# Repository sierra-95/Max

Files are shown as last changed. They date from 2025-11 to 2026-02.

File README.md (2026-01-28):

# Project Max

## Table of Contents

1. [Introduction](#introduction)
2. [Robot Variants](#robot-variants)
3. [Project Implementation](#project-implementation)
4. [Getting Started](#getting-started)
5. [Launching Max](#launching-max)
6. [License](#license)
7. [Contributors](#contributors)

---

## Introduction

**Max** is an Autonomous Mobile Robot (AMR) designed for **mapping, localization, and autonomous navigation** using **ROS 2 Humble Hawksbill**.

The project explores both **LiDAR-based SLAM** and **visual SLAM (VSLAM)**, along with real-world robotic tasks such as object detection and agricultural disease detection.

---

## Robot Variants

Two physical versions of Max were developed:

* **Skid-Steer Robot**

  * LiDAR-based SLAM
  * Autonomous navigation using Nav2
  * [Potato disease detection](https://github.com/sierra-95/potato_disease_detection) and Color cube detection using Logitech camera
  * Mechanical loading and offloading mechanism

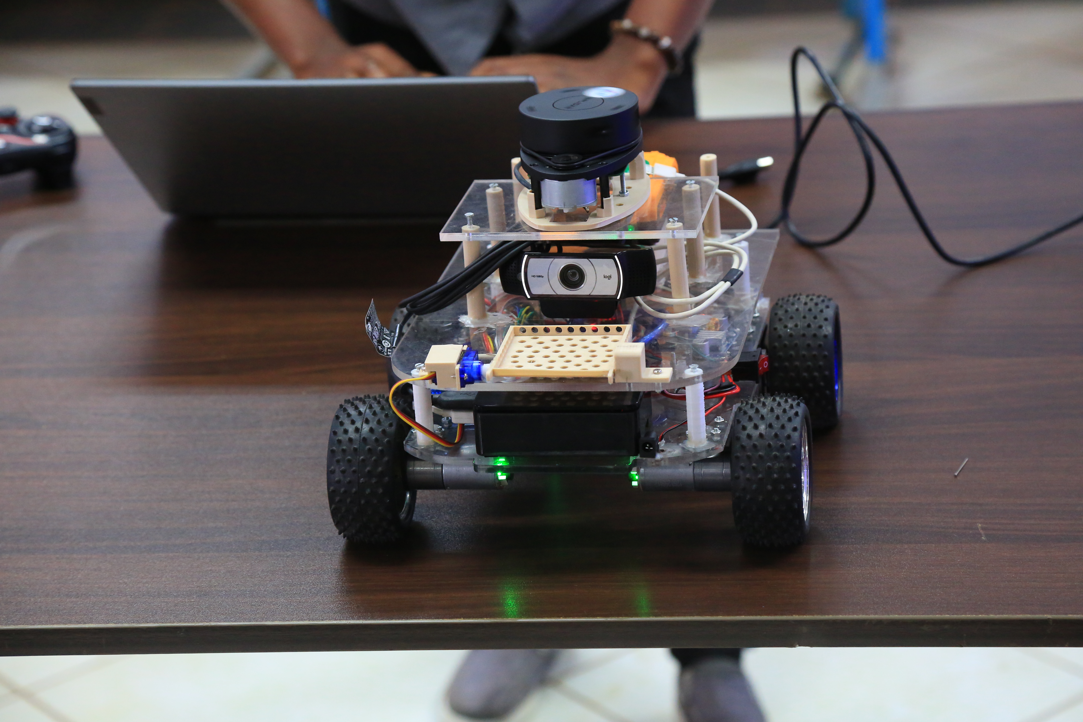
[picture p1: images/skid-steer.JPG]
Skid Steer


* **Differential Drive Robot - Beta**

  * LiDAR-based SLAM
  * Visual SLAM (VSLAM) using depth camera
  * Emergency stop button (motor cutoff)
  * Software-based proximity safety: reduces speed as the robot approaches obstacles, with RGB LED indication

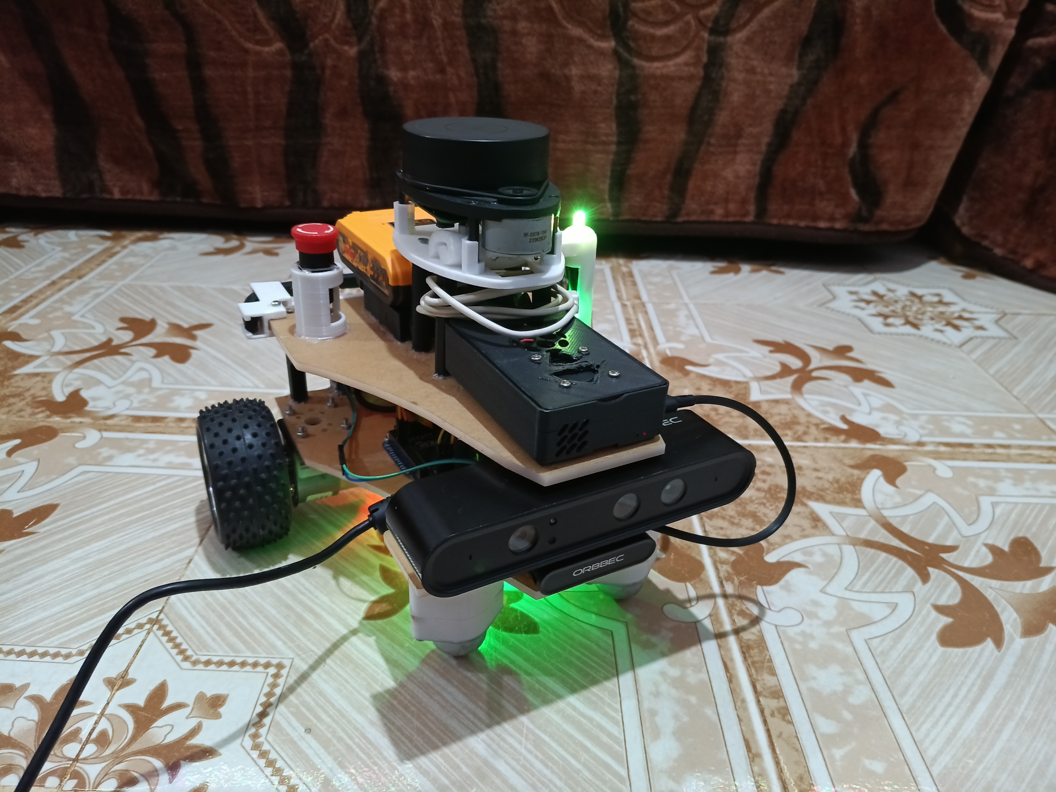
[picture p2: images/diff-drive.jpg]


---

## Project Implementation

### 1. Hardware Components

* **Raspberry Pi 4** – Main onboard computer
* **RPLidar A1** – 2D LiDAR for SLAM and navigation
* **Orbbec Astra Pro Depth Camera** – Used for VSLAM
* **Logitech C290 USB Camera** – Used for potato disease detection and color cube detection
* **JGB37-520 12V 110 RPM DC Motors (with encoders)**
* **L298N Motor Driver**
* **20V 2A Ingco Drill Battery** – Power source
* **Arduino Mega 2560** – Low-level motor control and encoder processing

---

### 2. Electrical design
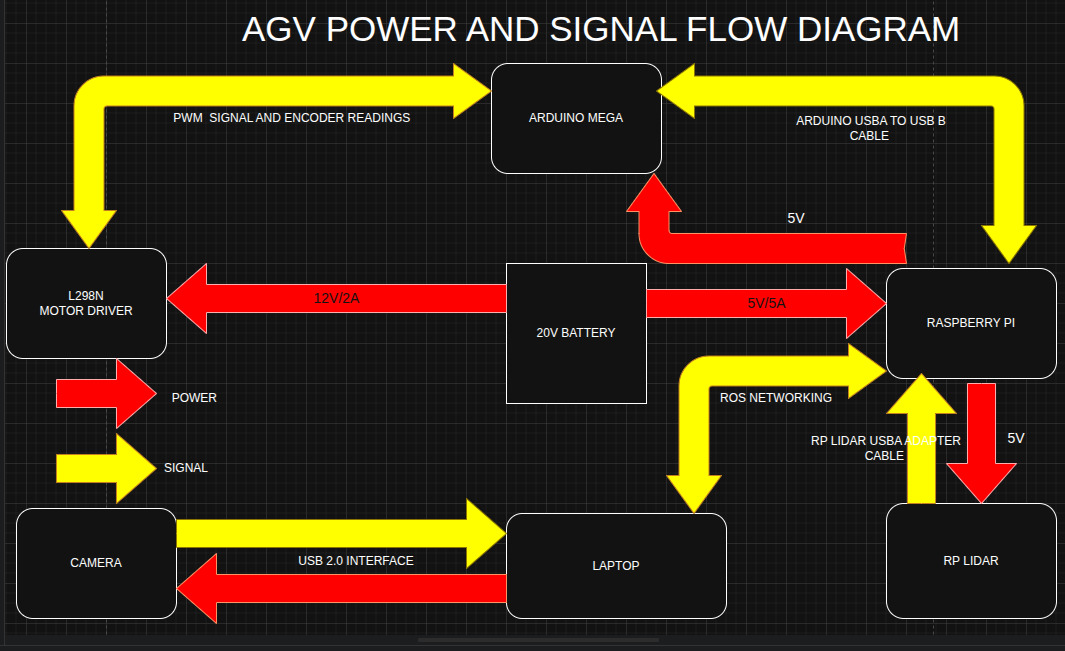
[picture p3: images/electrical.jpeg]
PCB

### 3. Digital Twin

A **Digital Twin** is a virtual representation of the physical robot and its environment.

In Project Max:

* **Gazebo** was used for physics-based simulation

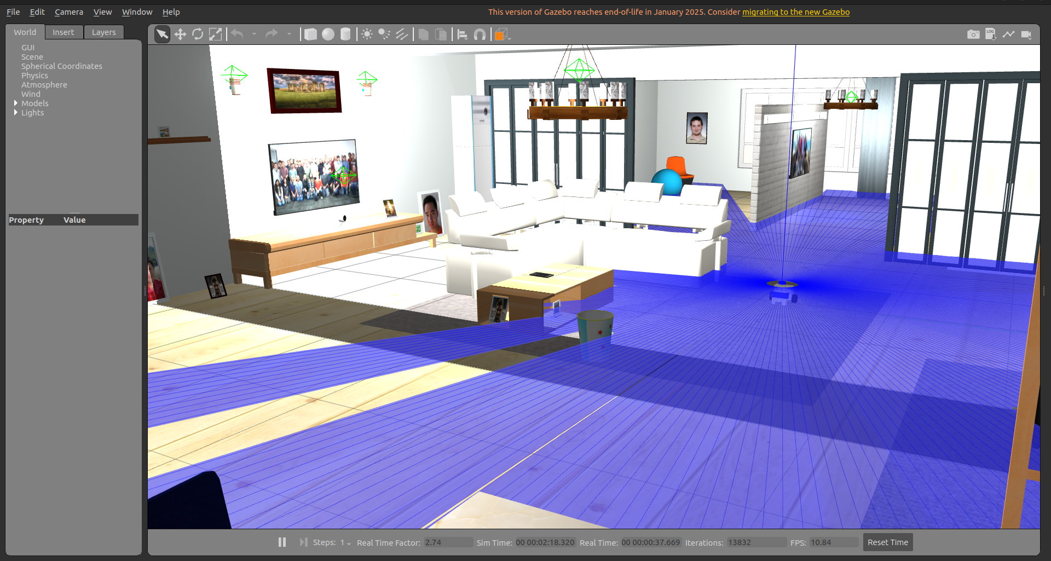
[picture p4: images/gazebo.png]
Gazebo


* **RViz** was used for visualization of:

  * Robot state
  * TF Structure
  * Maps and navigation goals

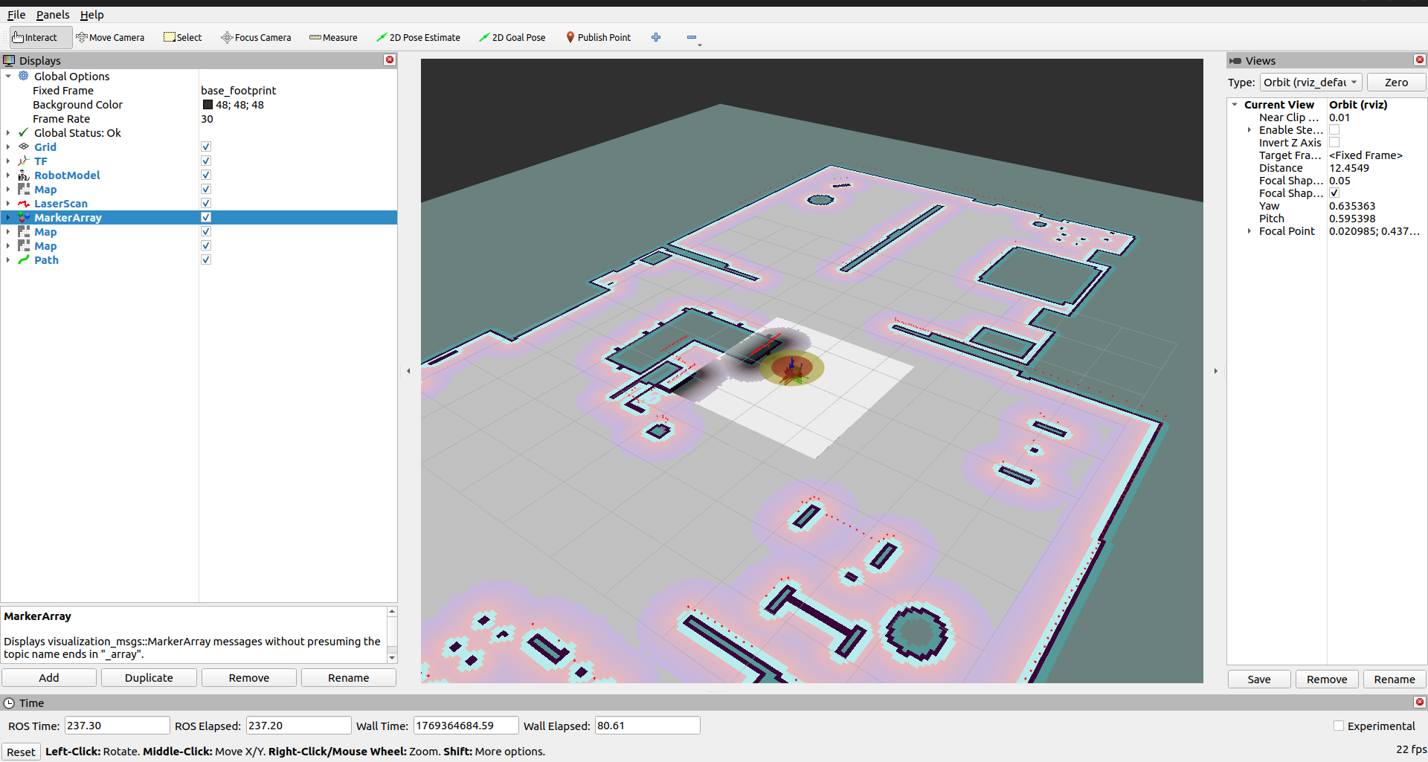
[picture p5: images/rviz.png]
Rviz

#### TF tree
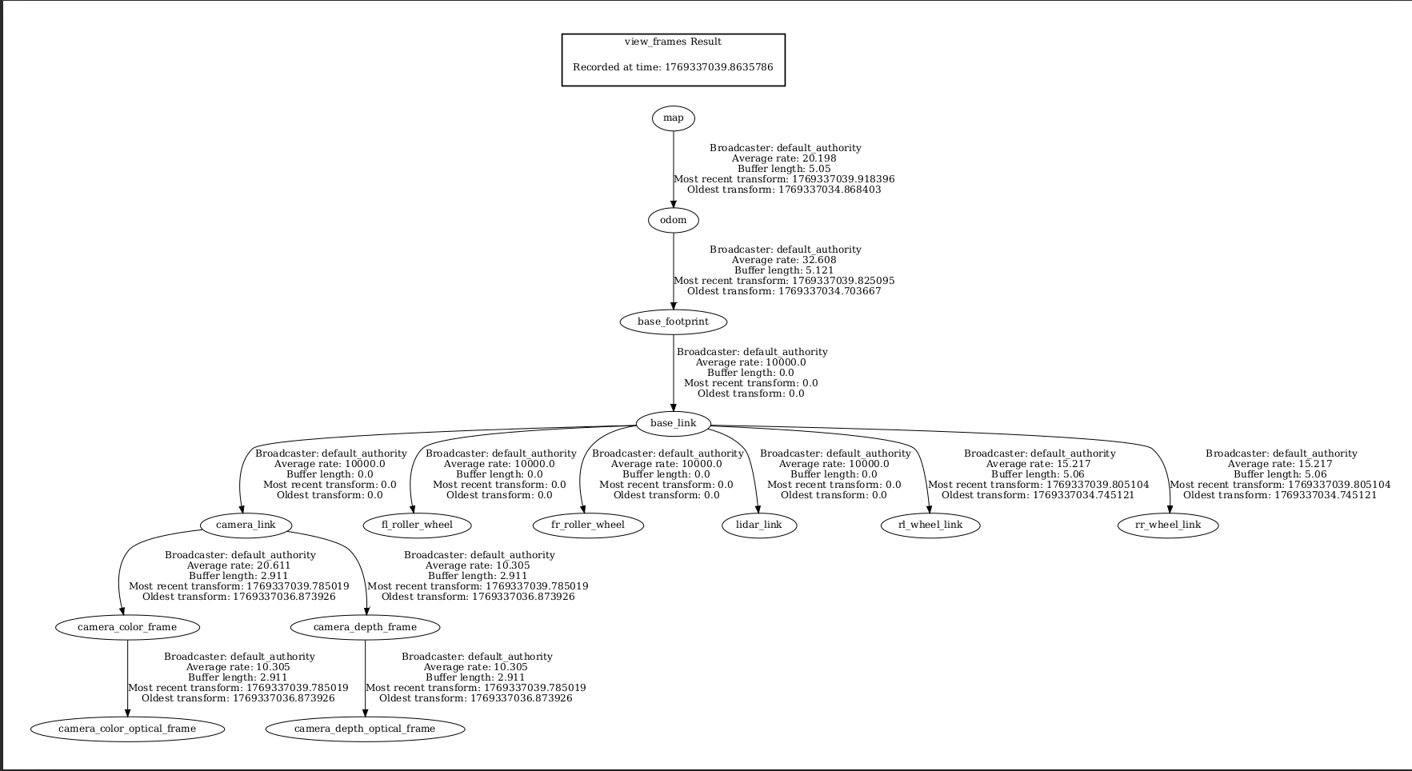
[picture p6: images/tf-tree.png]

---
### 4. SLAM

**Simultaneous Localization and Mapping (SLAM)** is the process of building a map of an unknown environment while simultaneously estimating the robot’s position within that map.

In Max:

* A **2D occupancy grid map** was generated using **LiDAR scans** and **Wheel odometry**, computed from encoder counts
* The resulting map was later used by **Nav2** for autonomous navigation and path planning

---

### 5. Visual SLAM (VSLAM)

**Visual SLAM (VSLAM)** uses camera data instead of (or in addition to) LiDAR.

In this approach:

* A **3D map or point cloud** is built using a **depth camera**.
* Compared to 2D SLAM, VSLAM provides more spatial information

> Note: Although LiDAR–VSLAM sensor fusion is possible, this project used **VSLAM independently** without fusion.

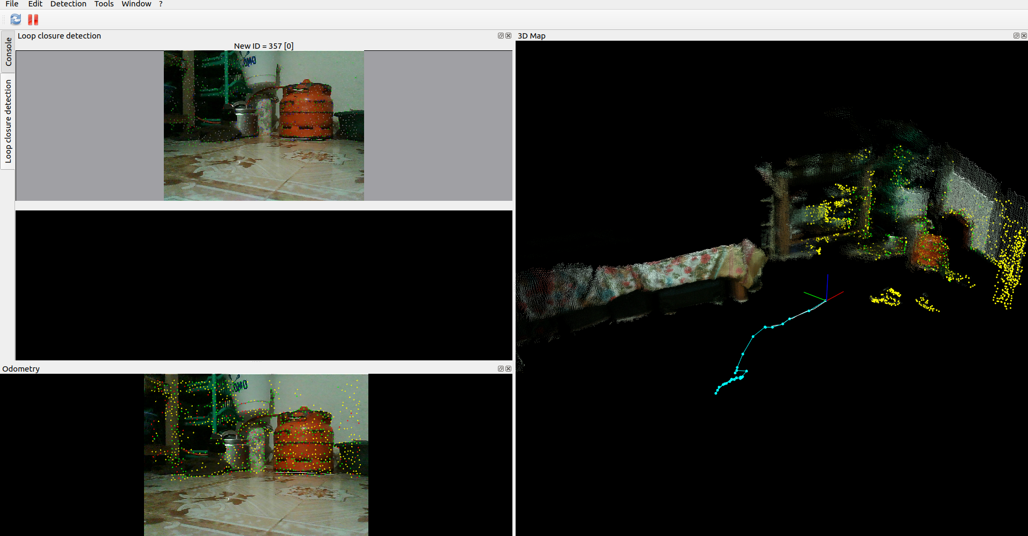
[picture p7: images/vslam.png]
Vslam


---

## Getting Started

### Clone the Repository

```bash
# Create workspace
mkdir -p max_ws/src && cd max_ws/src

# Clone repository
git clone https://github.com/sierra-95/Max.git
```

---

### Install Dependencies

```bash
# Update ROS dependency database
sudo rosdep update

# Install dependencies
rosdep install --from-paths src --ignore-src -r -y
```

---

### Build the Workspace

```bash
# Checkout the preferred branch
git checkout main

# Build the packages
colcon build --symlink-install
. install/setup.bash
```

---

## Launching Max

### Simulated Robot

```bash
ros2 launch max_bringup max.simulated.launch.py world_name:=small_house
```

---

### Real Robot

#### On the Raspberry Pi

```bash
ros2 launch rplidar_ros rplidar_a1_launch.py serial_port:=/dev/ttyUSB0 serial_baudrate:=115200 frame_id:=lidar_link
```

```bash
#Add the argument `use_rtab:=true` if using VSLAM.
ros2 launch max_bringup max.launch.py
```
#### On the Laptop

```bash
#Add the argument `use_rtab:=true` if using VSLAM.
ros2 launch max_bringup max.launch.py use_master:=true

# If using VSLAM
ros2 launch astra_camera astra_pro.launch.xml
```

---

## License

This project is **open source**.

## Contributors
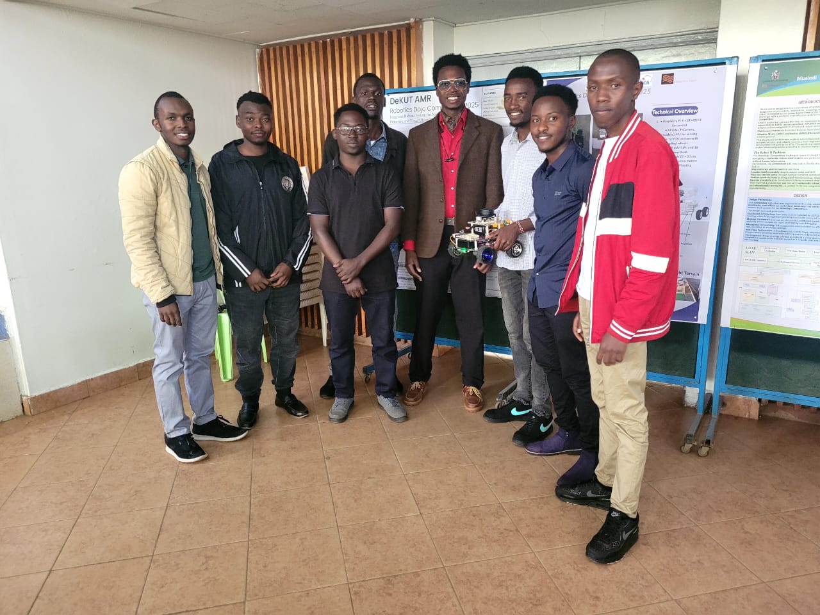
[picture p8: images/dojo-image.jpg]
Dojo Image


| Name | Profile |
|---|---|
| Michael Machohi | [sierra-95](https://github.com/sierra-95) |
| Paul Migwi | [Paul-Migwi](https://github.com/Paul-Migwi) |
| James Gathirwa  | [gathirwa011a](https://www.linkedin.com/in/gathirwa011a) |
| Brian Kiprono | [Kiprono1385](https://github.com/Kiprono1385) |
| Moses Mwangi | [moses-kangethe](https://www.linkedin.com/in/moses-kangethe) |
| Zebby Akach | [ZEBAYA](https://github.com/ZEBAYA) |

---

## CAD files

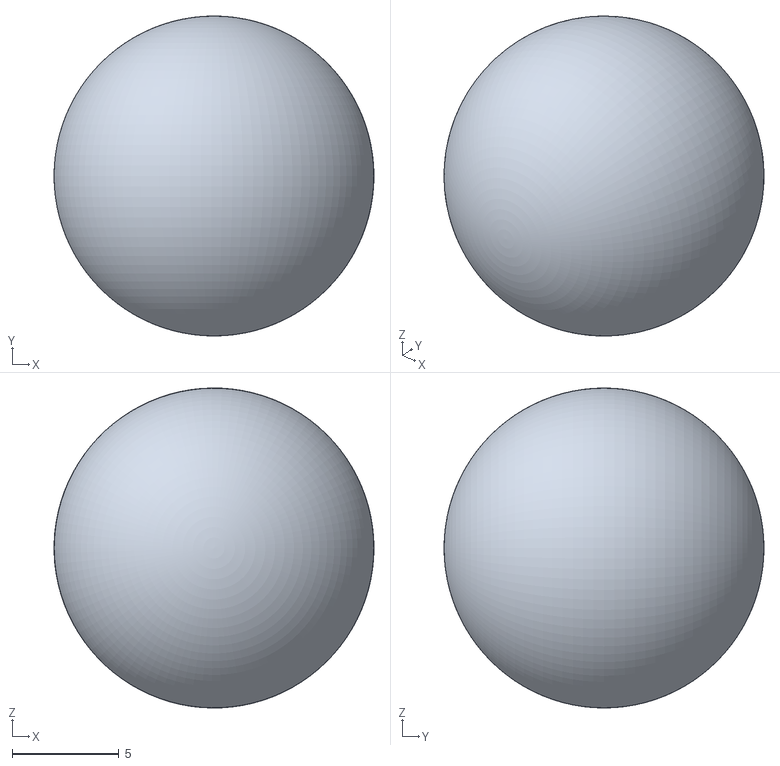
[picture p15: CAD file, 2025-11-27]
max_description/meshes/fl_roller_wheel.stl
15.0 x 15.0 x 15.0

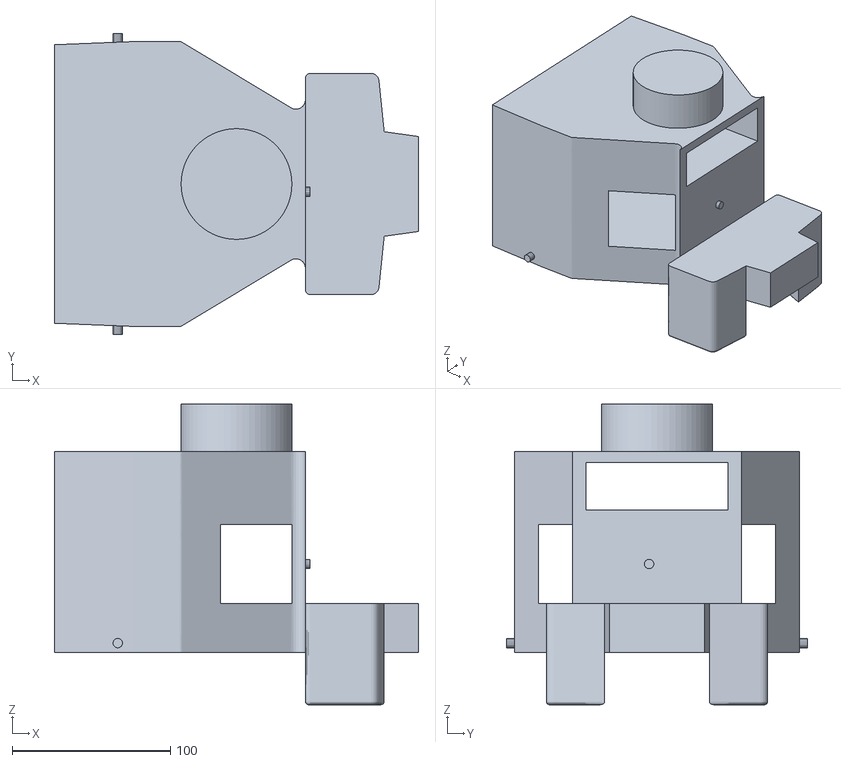
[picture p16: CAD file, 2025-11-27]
max_description/meshes/base_link.stl
230.0 x 190.0 x 190.0

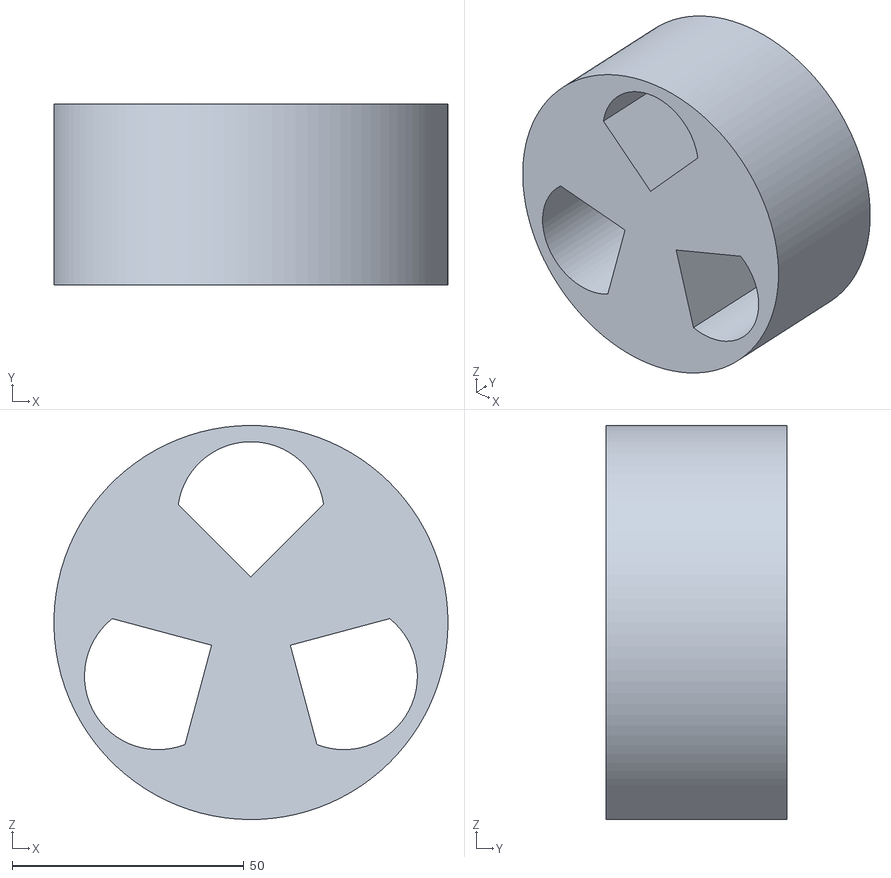
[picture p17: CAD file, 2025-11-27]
max_description/meshes/rr_wheel_link.stl
85.0 x 39.0 x 85.0

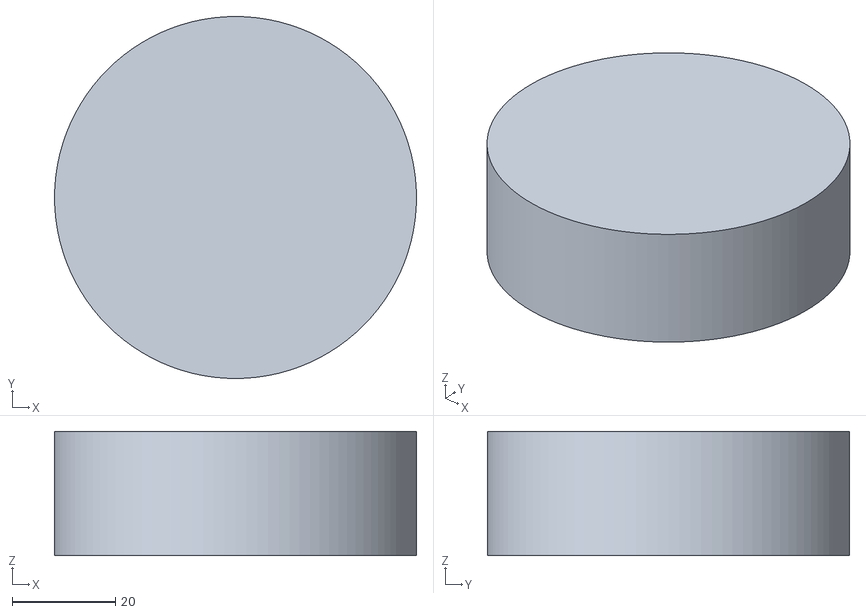
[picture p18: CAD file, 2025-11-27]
max_description/meshes/lidar_link.stl
70.0 x 70.0 x 24.0

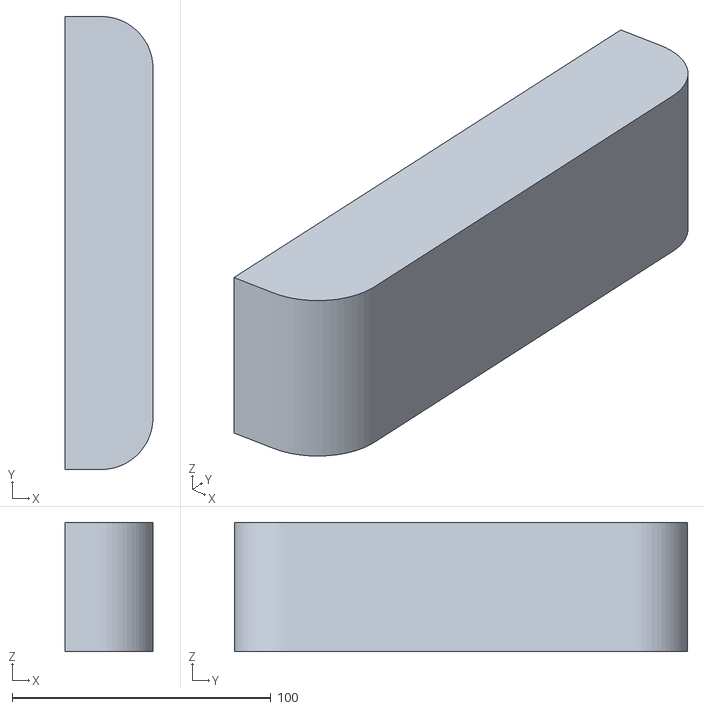
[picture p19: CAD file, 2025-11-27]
max_description/meshes/camera_link.stl
34.0 x 175.0 x 50.0

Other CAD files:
max_description/meshes/fr_roller_wheel.stl
max_description/meshes/rl_wheel_link.stl

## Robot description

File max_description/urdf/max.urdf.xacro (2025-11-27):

<?xml version="1.0"?>

<robot name="max" xmlns:xacro="http://www.ros.org/wiki/xacro">
    
    <xacro:arg name="is_sim" default="true"/>
    <xacro:arg name="is_ignition" default="false"/>
    
    <xacro:include filename="$(find max_description)/urdf/materials.xacro" />
    <xacro:include filename="$(find max_description)/urdf/max.gazebo.xacro" />
    <xacro:include filename="$(find max_description)/urdf/trans.xacro" />
    <xacro:include filename="$(find max_description)/urdf/ros2_control.xacro" />

    <link name="base_footprint"/>
    
    <link name="base_link">
        <inertial>
            <origin xyz="-0.02395632727900399 -2.01772150977478e-07 0.09083712403458968" rpy="0 0 0"/>
            <mass value="2.2280671864878805"/>
            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
        </inertial>
        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
    </link>

    <link name="rr_wheel_link">
        <inertial>
            <origin xyz="-2.2343238370581275e-15 -0.015512778351276846 1.3877787807814457e-17" rpy="0 0 0"/>
            <mass value="0.14404511942595016"/>
            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
        </inertial>
        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
    </link>

    <link name="rl_wheel_link">
        <inertial>
            <origin xyz="-2.220446049250313e-16 0.015512778351276832 6.245004513516506e-17" rpy="0 0 0"/>
            <mass value="0.1440451194259502"/>
            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
        </inertial>
        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
    </link>

    <link name="lidar_link">
        <inertial>
            <origin xyz="-6.154361288395009e-18 -4.3080529018765064e-17 0.012000000000000038" rpy="0 0 0"/>
            <mass value="0.09790459345647239"/>
            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
        </inertial>
        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
    </link>

    <link name="camera_link">
        <inertial>
            <origin xyz="0.013632302340116711 -8.413408858487514e-17 8.326672684688674e-17" rpy="0 0 0"/>
            <mass value="0.30616096974630597"/>
            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
        </inertial>
        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
    </link>

    <link name="fr_roller_wheel">
        <inertial>
            <origin xyz="1.3877787807814457e-17 6.938893903907228e-18 -5.204170427930421e-18" rpy="0 0 0"/>
            <mass value="0.01387209506100743"/>
            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
        </inertial>
        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
    </link>

    <link name="fl_roller_wheel">
        <inertial>
            <origin xyz="1.3877787807814457e-17 -6.938893903907228e-18 1.9949319973733282e-17" rpy="0 0 0"/>
            <mass value="0.01387209506100743"/>
            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
        </inertial>
        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
    </link>

    <joint name="base_joint" type="fixed">
        <parent link="base_footprint"/>
        <child link="base_link"/>
        <origin xyz="0 0 0.0425" rpy="0 0 0"/>
    </joint>

    <joint name="rr_joint" type="continuous">
        <origin xyz="-0.075 -0.095 0" rpy="0 0 0"/>
        <parent link="base_link"/>
        <child link="rr_wheel_link"/>
        <axis xyz="0.0 1.0 0.0"/>
    </joint>

    <joint name="rl_joint" type="continuous">
        <origin xyz="-0.075 0.095 0" rpy="0 0 0"/>
        <parent link="base_link"/>
        <child link="rl_wheel_link"/>
        <axis xyz="0.0 1.0 0.0"/>
    </joint>

    <joint name="lidar_joint" type="fixed">
        <origin xyz="0.0 0.0 0.151" rpy="0 0 0"/>
        <parent link="base_link"/>
        <child link="lidar_link"/>
    </joint>

    <joint name="camera_joint" type="fixed">
        <origin xyz="0.046567 -0.005 0.05" rpy="0 0 0"/>
        <parent link="base_link"/>
        <child link="camera_link"/>
    </joint>

    <joint name="fr_joint" type="fixed">
        <origin xyz="0.07 -0.055 -0.035" rpy="0 0 0"/>
        <parent link="base_link"/>
        <child link="fr_roller_wheel"/>
    </joint>

    <joint name="fl_joint" type="fixed">
        <origin xyz="0.07 0.055 -0.035" rpy="0 0 0"/>
        <parent link="base_link"/>
        <child link="fl_roller_wheel"/>
    </joint>
</robot>

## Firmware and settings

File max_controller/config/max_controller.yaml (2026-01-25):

controller_manager:
  ros__parameters:
    update_rate: 100

    joint_state_broadcaster:
      type: joint_state_broadcaster/JointStateBroadcaster

    simple_velocity_controller:
      type: velocity_controllers/JointGroupVelocityController

    max_controller:
      type: diff_drive_controller/DiffDriveController


simple_velocity_controller:
  ros__parameters:
    joints:
      - rl_joint
      - rr_joint

max_controller:
  ros__parameters:
    type: diff_drive_controller/DiffDriveController
    use_stamped_vel: false
    left_wheel_names: ["rl_joint"]
    right_wheel_names: ["rr_joint"]
    
    publish_rate: 50.0
    pose_covariance_diagonal : [0.001, 0.001, 1.0e-3, 1.0e-3, 1.0e-3, 0.01]
    twist_covariance_diagonal: [0.001, 0.001, 1.0e-3, 1.0e-3, 1.0e-3, 0.01]
    
    wheel_separation: 0.232
    wheel_radius: 0.0425
    
    left_wheel_radius_multiplier: 1.0
    right_wheel_radius_multiplier: 1.0
    wheel_separation_multiplier: 1.0  
    
    cmd_vel_timeout: 0.25
    odom_frame_id: odom
    base_frame_id: base_footprint
    publish_limited_velocity: true
    publish_wheel_data: true
    enable_odom_tf: true

    linear:
      x:
        has_velocity_limits: true
        max_velocity: 0.5
        min_velocity: -0.5
        has_acceleration_limits: true
        max_acceleration: 0.8
        min_acceleration: -0.8
        has_jerk_limits: false
    
    angular:
      z:
        has_velocity_limits: true
        max_velocity: 3.0
        min_velocity: -3.0
        has_acceleration_limits: true
        max_acceleration: 3.0
        min_acceleration: -3.0
        has_jerk_limits: false

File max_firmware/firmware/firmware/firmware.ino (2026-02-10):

#include <PID_v1.h>

// L298N H-Bridge Connection PINs
#define L298N_enA 5  // PWM
#define L298N_enB 6  // PWM
#define L298N_in4 42 //30  // Dir Motor B
#define L298N_in3 43 //31  // Dir Motor B
#define L298N_in2 44 //32  // Dir Motor A
#define L298N_in1 45 //33  // Dir Motor A

// Wheel Encoders Connection PINs
#define right_encoder_phaseA 18  // Interrupt 
#define right_encoder_phaseB 19  
#define left_encoder_phaseA 20   // Interrupt
#define left_encoder_phaseB 21

// Encoders
unsigned int right_encoder_counter = 0;
unsigned int left_encoder_counter = 0;
String right_wheel_sign = "p";  // 'p' = positive, 'n' = negative
String left_wheel_sign = "p";  // 'p' = positive, 'n' = negative
unsigned long last_millis = 0;
const unsigned long interval = 100;

// Interpret Serial Messages
bool is_right_wheel_cmd = false;
bool is_left_wheel_cmd = false;
bool is_right_wheel_forward = true;
bool is_left_wheel_forward = true;
char value[] = "00.00";
uint8_t value_idx = 0;
bool is_cmd_complete = false;

// PID
// Setpoint - Desired
double right_wheel_cmd_vel = 0.0;     // rad/s
double left_wheel_cmd_vel = 0.0;      // rad/s
// Input - Measurement
double right_wheel_meas_vel = 0.0;    // rad/s
double left_wheel_meas_vel = 0.0;     // rad/s
// Output - Command
double right_wheel_cmd = 0.0;             // 0-255
double left_wheel_cmd = 0.0;              // 0-255
// Tuning
double Kp_r = 11.5;
double Ki_r = 7.5;
double Kd_r = 0.1;
double Kp_l = 11.5;
double Ki_l = 8.3;
double Kd_l = 0.1;
// Controller
PID rightMotor(&right_wheel_meas_vel, &right_wheel_cmd, &right_wheel_cmd_vel, Kp_r, Ki_r, Kd_r, DIRECT);
PID leftMotor(&left_wheel_meas_vel, &left_wheel_cmd, &left_wheel_cmd_vel, Kp_l, Ki_l, Kd_l, DIRECT);

void setup() {
  // Init L298N H-Bridge Connection PINs
  pinMode(L298N_enA, OUTPUT);
  pinMode(L298N_enB, OUTPUT);
  pinMode(L298N_in1, OUTPUT);
  pinMode(L298N_in2, OUTPUT);
  pinMode(L298N_in3, OUTPUT);
  pinMode(L298N_in4, OUTPUT);

  // Set Motor Rotation Direction
  digitalWrite(L298N_in1, HIGH);
  digitalWrite(L298N_in2, LOW);
  digitalWrite(L298N_in3, HIGH);
  digitalWrite(L298N_in4, LOW);

  rightMotor.SetMode(AUTOMATIC);
  leftMotor.SetMode(AUTOMATIC);
  Serial.begin(115200);

  // Init encoders
  pinMode(right_encoder_phaseB, INPUT);
  pinMode(left_encoder_phaseB, INPUT);
  // Set Callback for Wheel Encoders Pulse
  attachInterrupt(digitalPinToInterrupt(right_encoder_phaseA), rightEncoderCallback, RISING);
  attachInterrupt(digitalPinToInterrupt(left_encoder_phaseA), leftEncoderCallback, RISING);
}

void loop() {
  // Read and Interpret Wheel Velocity Commands
  if (Serial.available())
  {
    char chr = Serial.read();
    // Right Wheel Motor
    if(chr == 'r')
    {
      is_right_wheel_cmd = true;
      is_left_wheel_cmd = false;
      value_idx = 0;
      is_cmd_complete = false;
    }
    // Left Wheel Mo tor
    else if(chr == 'l')
    {
      is_right_wheel_cmd = false;
      is_left_wheel_cmd = true;
      value_idx = 0;
    }
    // Positive direction
    else if(chr == 'p')
    {
      if(is_right_wheel_cmd && !is_right_wheel_forward)
      {
        // change the direction of the rotation
        digitalWrite(L298N_in1, HIGH - digitalRead(L298N_in1));
        digitalWrite(L298N_in2, HIGH - digitalRead(L298N_in2));
        is_right_wheel_forward = true;
      }
      else if(is_left_wheel_cmd && !is_left_wheel_forward)
      {
        // change the direction of the rotation
        digitalWrite(L298N_in3, HIGH - digitalRead(L298N_in3));
        digitalWrite(L298N_in4, HIGH - digitalRead(L298N_in4));
        is_left_wheel_forward = true;
      }
    }
    // Negative direction
    else if(chr == 'n')
    {
      if(is_right_wheel_cmd && is_right_wheel_forward)
      {
        // change the direction of the rotation
        digitalWrite(L298N_in1, HIGH - digitalRead(L298N_in1));
        digitalWrite(L298N_in2, HIGH - digitalRead(L298N_in2));
        is_right_wheel_forward = false;
      }
      else if(is_left_wheel_cmd && is_left_wheel_forward)
      {
        // change the direction of the rotation
        digitalWrite(L298N_in3, HIGH - digitalRead(L298N_in3));
        digitalWrite(L298N_in4, HIGH - digitalRead(L298N_in4));
        is_left_wheel_forward = false;
      }
    }
    // Separator
    else if(chr == ',')
    {
      if(is_right_wheel_cmd)
      {
        right_wheel_cmd_vel = atof(value);
      }
      else if(is_left_wheel_cmd)
      {
        left_wheel_cmd_vel = atof(value);
        is_cmd_complete = true;
      }
      // Reset for next command
      value_idx = 0;
      value[0] = '0';
      value[1] = '0';
      value[2] = '.';
      value[3] = '0';
      value[4] = '0';
      value[5] = '\0';
    }
    // Command Value
    else
    {
      if(value_idx < 5)
      {
        value[value_idx] = chr;
        value_idx++;
      }
    }
  }

  // Encoder
  unsigned long current_millis = millis();
  if(current_millis - last_millis >= interval)
  {
    right_wheel_meas_vel = (10 * right_encoder_counter * (60.0/3930.0)) * 0.10472;
    left_wheel_meas_vel = (10 * left_encoder_counter * (60.0/3930.0)) * 0.10472;
    
    rightMotor.Compute();
    leftMotor.Compute();

    // Ignore commands smaller than inertia
    if(right_wheel_cmd_vel == 0.0)
    {
      right_wheel_cmd = 0.0;
    }
    if(left_wheel_cmd_vel == 0.0)
    {
      left_wheel_cmd = 0.0;
    }

    String encoder_read = "r" + right_wheel_sign + String(right_wheel_meas_vel) + ",l" + left_wheel_sign + String(left_wheel_meas_vel) + ",";
    Serial.println(encoder_read);
    last_millis = current_millis;
    right_encoder_counter = 0;
    left_encoder_counter = 0;

    analogWrite(L298N_enA, right_wheel_cmd);
    analogWrite(L298N_enB, left_wheel_cmd);
  }
}

// New pulse from Right Wheel Encoder
void rightEncoderCallback()
{
  if(digitalRead(right_encoder_phaseB) == HIGH)
  {
    right_wheel_sign = "p";
  }
  else
  {
    right_wheel_sign = "n";
  }
  right_encoder_counter++;
}

// New pulse from Left Wheel Encoder
void leftEncoderCallback()
{
  if(digitalRead(left_encoder_phaseB) == HIGH)
  {
    left_wheel_sign = "n";
  }
  else
  {
    left_wheel_sign = "p";
  }
  left_encoder_counter++;
}

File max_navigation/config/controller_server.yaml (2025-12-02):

controller_server:
  ros__parameters:
    use_sim_time: true
    controller_frequency: 20.0
    min_x_velocity_threshold: 0.001
    min_y_velocity_threshold: 0.5
    min_theta_velocity_threshold: 0.001
    failure_tolerance: 0.3
    progress_checker_plugin: "progress_checker"
    goal_checker_plugins: ["general_goal_checker"]
    controller_plugins: ["FollowPath"]
    odom_topic: /max_controller/odom

    # Progress checker parameters
    progress_checker:
      plugin: "nav2_controller::SimpleProgressChecker"
      required_movement_radius: 0.5
      movement_time_allowance: 10.0
    # Goal checker parameters
    general_goal_checker:
      plugin: "nav2_controller::SimpleGoalChecker"
      xy_goal_tolerance: 0.25
      yaw_goal_tolerance: 0.25
      stateful: True
    
    # PD Motion Planner parameters
    # FollowPath:
    #   plugin: "max_motion::PDMotionPlanner"
    #   kp: 2.0
    #   kd: 0.1
    #   max_linear_velocity: 0.3
    #   max_angular_velocity: 1.0
    #   step_size: 0.1

    # Pure Pursuit parameters
    # PurePursuit:
    #   plugin: "max_motion::PurePursuit"
    #   look_ahead_distance: 0.5
    #   max_linear_velocity: 0.3
    #   max_angular_velocity: 1.0
    
    # RPP parameters
    FollowPath:
      plugin: "nav2_regulated_pure_pursuit_controller::RegulatedPurePursuitController"
      desired_linear_vel: 0.5
      lookahead_dist: 0.6
      min_lookahead_dist: 0.3
      max_lookahead_dist: 0.9
      lookahead_time: 1.5
      rotate_to_heading_angular_vel: 2.5
      transform_tolerance: 0.2
      use_velocity_scaled_lookahead_dist: false
      min_approach_linear_velocity: 0.05
      approach_velocity_scaling_dist: 1.0
      use_collision_detection: true
      max_allowed_time_to_collision_up_to_carrot: 1.0
      use_regulated_linear_velocity_scaling: true
      use_cost_regulated_linear_velocity_scaling: false
      regulated_linear_scaling_min_radius: 0.9
      regulated_linear_scaling_min_speed: 0.25
      use_fixed_curvature_lookahead: false
      curvature_lookahead_dist: 1.0
      use_rotate_to_heading: true
      rotate_to_heading_min_angle: 0.785
      max_angular_accel: 3.2
      max_robot_pose_search_dist: 10.0
      interpolate_curvature_after_goal: false
      cost_scaling_dist: 0.3
      cost_scaling_gain: 1.0
      inflation_cost_scaling_factor: 3.0

local_costmap:
  local_costmap:
    ros__parameters:
      update_frequency: 5.0
      publish_frequency: 2.0
      global_frame: odom
      robot_base_frame: base_link
      use_sim_time: true
      rolling_window: true
      width: 3
      height: 3
      resolution: 0.05
      robot_radius: 0.1
      plugins: ["obstacle_layer", "inflation_layer"]
      inflation_layer:
        plugin: "nav2_costmap_2d::InflationLayer"
        cost_scaling_factor: 3.0
        inflation_radius: 0.55
      obstacle_layer:
        plugin: "nav2_costmap_2d::ObstacleLayer"
        enabled: True
        observation_sources: scan
        scan:
          topic: /scan
          max_obstacle_height: 2.0
          clearing: True
          marking: True
          data_type: "LaserScan"
          raytrace_max_range: 3.0
          raytrace_min_range: 0.0
          obstacle_max_range: 2.5
          obstacle_min_range: 0.0
      always_send_full_costmap: True

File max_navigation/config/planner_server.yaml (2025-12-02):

planner_server:
  ros__parameters:
    expected_planner_frequency: 1.0
    use_sim_time: true
    planner_plugins: ["GridBased"]

    # Dijkstra Planner parameters
    # GridBased:
    #   plugin: "max_planning::DijkstraPlanner"

    # A* Planner parameters
    # GridBasedFast:
    #   plugin: "max_planning::AStarPlanner"
    # Smac 2D parameters
    GridBased:
      plugin: "nav2_smac_planner/SmacPlanner2D" # In Iron and older versions, "/" was used instead of "::"
      tolerance: 0.125                      # tolerance for planning if unable to reach exact pose, in meters
      downsample_costmap: false             # whether or not to downsample the map
      downsampling_factor: 1                # multiplier for the resolution of the costmap layer (e.g. 2 on a 5cm costmap would be 10cm)
      allow_unknown: true                   # allow traveling in unknown space
      max_iterations: 1000000               # maximum total iterations to search for before failing (in case unreachable), set to -1 to disable
      max_on_approach_iterations: 1000      # maximum number of iterations to attempt to reach goal once in tolerance
      max_planning_time: 2.0                # max time in s for planner to plan, smooth
      cost_travel_multiplier: 2.0           # Cost multiplier to apply to search to steer away from high cost areas. Larger values will place in the center of aisles more exactly (if non-`FREE` cost potential field exists) but take slightly longer to compute. To optimize for speed, a value of 1.0 is reasonable. A reasonable tradeoff value is 2.0. A value of 0.0 effective disables steering away from obstacles and acts like a naive binary search A*.
      use_final_approach_orientation: false # Whether to set the final path pose at the goal's orientation to the requested orientation (false) or in line with the approach angle so the robot doesn't rotate to heading (true)
      smoother:
        max_iterations: 1000
        w_smooth: 0.3
        w_data: 0.2
        tolerance: 1.0e-10

global_costmap:
  global_costmap:
    ros__parameters:
      update_frequency: 1.0
      publish_frequency: 1.0
      global_frame: map
      robot_base_frame: base_link
      use_sim_time: true
      robot_radius: 0.1
      resolution: 0.05
      track_unknown_space: true
      plugins: ["static_layer", "obstacle_layer", "inflation_layer"]
      obstacle_layer:
        plugin: "nav2_costmap_2d::ObstacleLayer"
        enabled: True
        observation_sources: scan
        scan:
          topic: /scan
          max_obstacle_height: 2.0
          clearing: True
          marking: True
          data_type: "LaserScan"
          raytrace_max_range: 3.0
          raytrace_min_range: 0.0
          obstacle_max_range: 2.5
          obstacle_min_range: 0.0
      static_layer:
        plugin: "nav2_costmap_2d::StaticLayer"
        map_topic: /map
        map_subscribe_transient_local: True
      inflation_layer:
        plugin: "nav2_costmap_2d::InflationLayer"
        cost_scaling_factor: 3.0
        inflation_radius: 0.55
      always_send_full_costmap: True

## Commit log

2025-11-12 Working on the urdf
    [base_link.stl, bl_wheel_link_1.stl, br_wheel_link_1.stl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]
2025-11-12 urdf basefootprint+baselink
    [fl_wheel_link.stl, fr_wheel_link.stl, max.urdf.xacro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]
2025-11-12 saving rviz in description package
    [materials.xacro, max.urdf.xacro]
2025-11-12 launch file is complete
    [max.gazebo.xacro, max.urdf.xacro, model-1_2.sdf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]
2025-11-13 Fixed gazebo sinking max
    [max.gazebo.xacro, max.urdf.xacro]
2025-11-13 Gazebo file okay
    [max.gazebo.xacro]
2025-11-13 added camera lnk to urdf
    [materials.xacro, max.gazebo.xacro, max.urdf.xacro]
2025-11-14 gazebo not launching
    [controllers.yaml, max.urdf.xacro, ros2_control.xacro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]
2025-11-14 plugins loading
    [bumperbot_controllers.yaml, trans.xacro]
2025-11-14 miraculously working
    [max_controller.yaml, trans.xacro]
2025-11-14 Car is moving--yay
    [max.urdf.xacro]
2025-11-14 testing diff drive
    [max_controller.yaml]
2025-11-16 trying to fix diff drive controller
    [max_controller.yaml]
2025-11-16 joint_state management
2025-11-16 wheel odometry feedback
2025-11-17 Chnaged Lidar Joint continuous to fixed - Lidar simulation failed
    [max.urdf.xacro]
2025-11-17 Launch file for hardware interface, is sim arg for description, useSimTrue: False
    [max.urdf.xacro, max_controller.yaml, ros2_control.xacro]
2025-11-17 Final launch file to start real and simulated robot
    [ros2_control.xacro]
2025-11-18 wheel stl files changed -: slotted
    [fl_wheel_link.stl, fr_wheel_link.stl, max.urdf.xacro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]
2025-11-18 firmware update on arduino code
2025-11-18 Getting ready to test arduino code
2025-11-19 Descripton update -mass reduction
    [base_link.stl, camera_link.stl, fl_wheel_link.stl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]
2025-11-19 fixed reserve on velocities
2025-11-19 Hardware interface running: ros2control get data all 4 wheels
2025-11-20 gazebo fotress+classic
    [max.urdf.xacro, ros2_control.xacro, trans.xacro]
2025-11-20 added small world and small warehouse
    [model.sdf]
2025-11-20 Finetuning Gazebo
    [max.gazebo.xacro, max_controller.yaml]
2025-11-21 Pose array for odometry
2025-11-21 Added Lidar to urdf - works in Gazebo
    [max.gazebo.xacro]
2025-11-21 starting on twist mux development
    [max_controller.yaml]
2025-11-24 Testing lidar custom implementation
2025-11-27 Beginning on diff drive controller
    [base_link.stl, camera_link.stl, fl_roller_wheel.stl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]
2025-11-27 fixed -1 in urdf, wheel going oppoiste
    [max.urdf.xacro]
2025-12-01 min range fix
    [max.gazebo.xacro]
2025-12-02 Nav2 working
    [controller_server.yaml]
2025-12-02 Working on behavior trees for bt navigator server
    [controller_server.yaml]
2025-12-02 Tuning velocity params
    [controller_server.yaml]
2025-12-02 Velocity for controller server update
2025-12-04 manually launch lidar
2025-12-04 fixed firmware pin mixing
    [firmware.ino, test_pwm_motors.ino]
2025-12-04 firmware update on wheel count per revolution
2025-12-04 Testing encoder readings
2025-12-09 waypoint server, firmware l298 Pin change
2025-12-17 Led testing
2025-12-17 added bumper bot description
    [base_link.STL, bumperbot.urdf.xacro, bumperbot_controller.yaml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]
2025-12-17 removed bumperbot from description
    [base_link.STL, bumperbot.urdf.xacro, bumperbot_controller.yaml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]
2026-01-23 Trying to fuse lidar with camera
2026-01-24 running on led pi
2026-01-25 build safety leds
2026-01-28 Updated electrical flow image
2026-02-10 pid solved
